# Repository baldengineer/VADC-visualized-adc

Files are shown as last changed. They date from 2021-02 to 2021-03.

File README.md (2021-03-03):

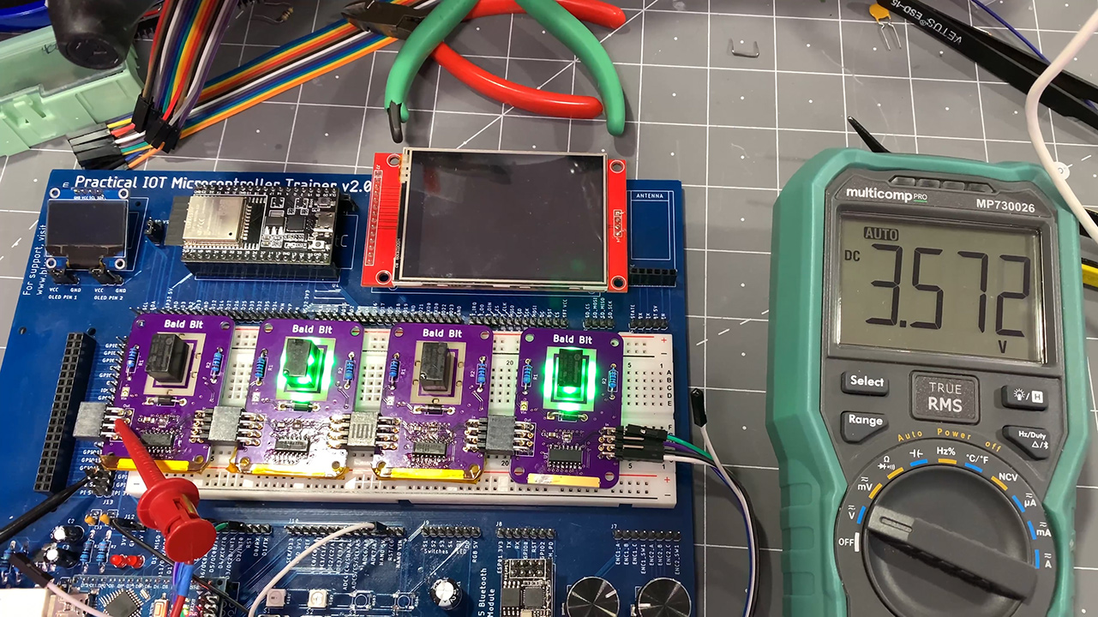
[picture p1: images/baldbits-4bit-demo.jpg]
Early Baldbits Demo


# VADC-visualized-adc
 Hardware project that shows how a SAR ADC works!

## Streaming notes
This project was created as a part of a [Bald Engineer Live Stream](https://twitch.tv/baldengineer). For stream-by-stream notes, [check out this repo](https://bald.ee/60-notes).

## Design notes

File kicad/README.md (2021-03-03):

# Visualized ADC KiCad Design Files
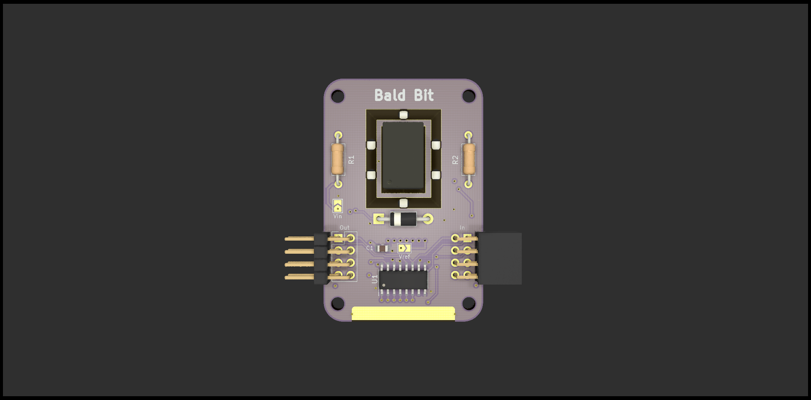
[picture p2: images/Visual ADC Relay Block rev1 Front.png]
Rendered vADC bit board


## Visual ADC Relay Block
Single bit block of the DAC inside of the ADC. The board contains a relay, R resistor, 2R resistor, LEDs, a shift register, and a buffer. 

The shift register and buffer control the relay and six LEDs individually. The relay controls the 2R resistor. 

The idea is to daisy chain these together. (So far, only tested with 4 bits.)

Board was fabricated with OSH Park's 4 layer service. The fiberglass material helps the reverse-mount LEDs glow.

## Sample-Hold-Compare
These files are schematic-only. I captured the breadboard circuit we used for the sample-and-hold amplifier and op-amp as a comparator.

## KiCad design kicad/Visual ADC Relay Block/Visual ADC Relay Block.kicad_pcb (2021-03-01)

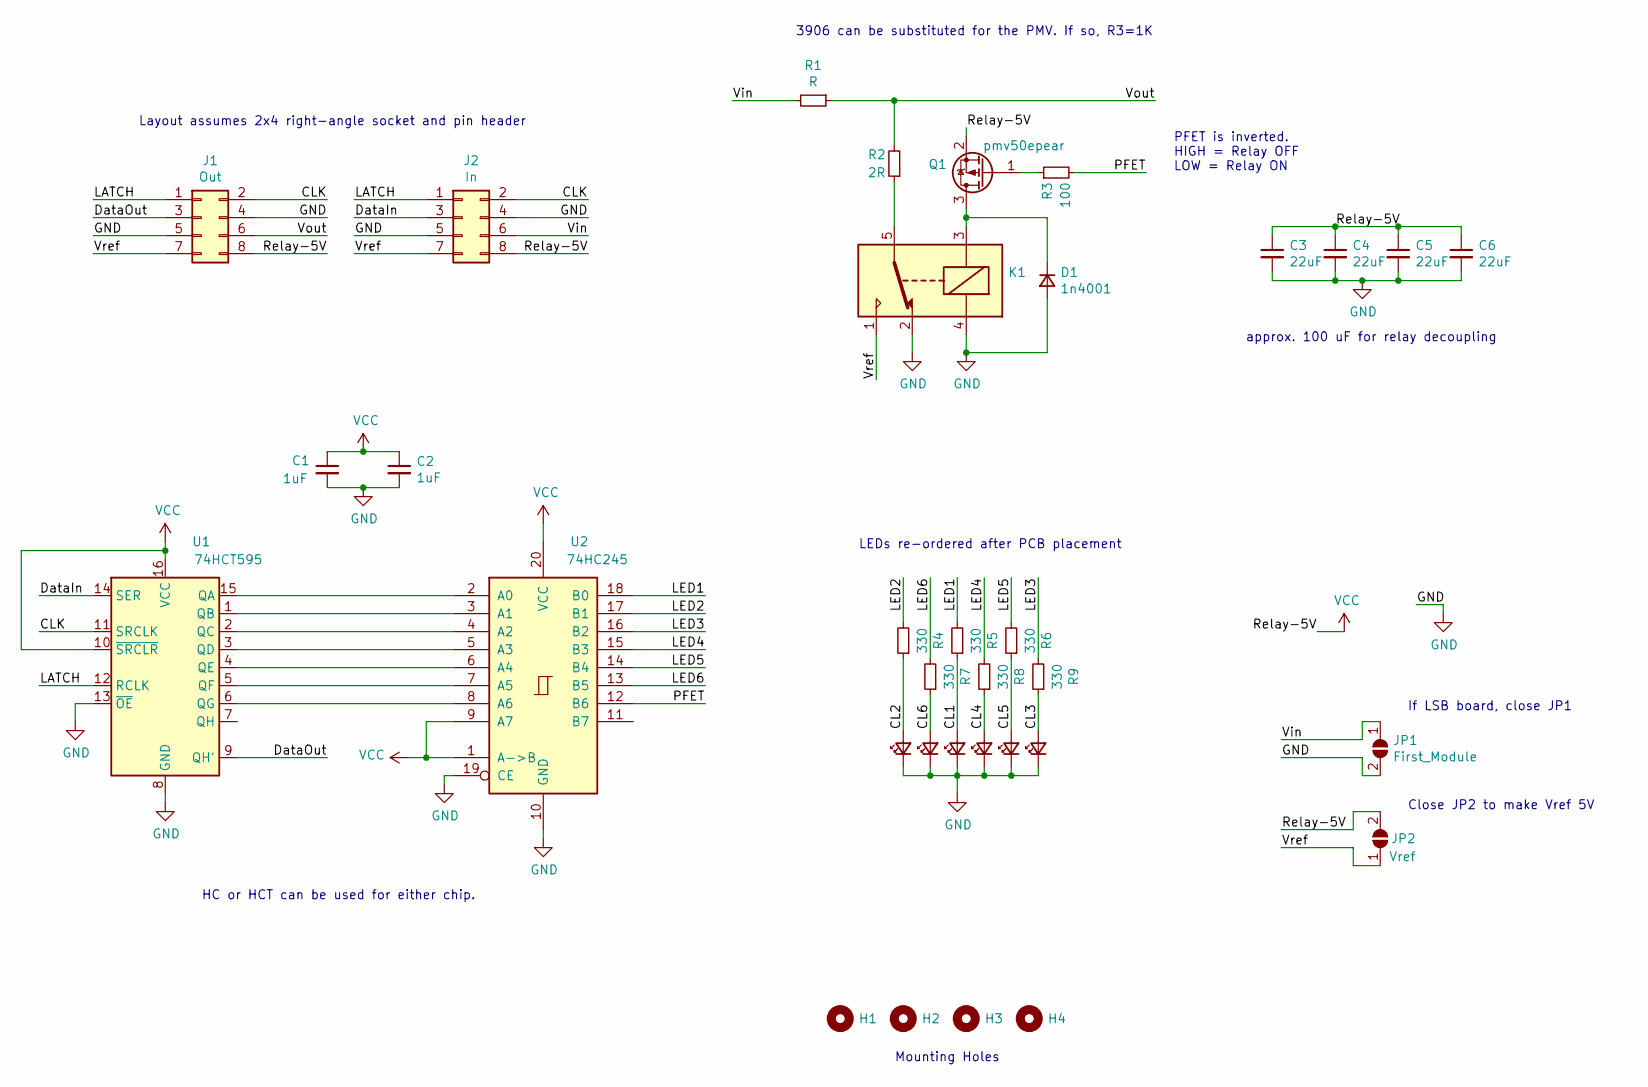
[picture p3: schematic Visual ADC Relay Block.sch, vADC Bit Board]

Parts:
C1, C2: 1uF; C_0805_2012Metric_Pad1.18x1.45mm_HandSolder
C3, C4, C5, C6: 22uF; C_0805_2012Metric_Pad1.18x1.45mm_HandSolder
D1: 1n4001; D_DO-41_SOD81_P10.16mm_Horizontal
D2, D3, D4, D5, D6, D7: LED_Small; LED_1206_3216Metric_ReverseMount_Hole1.8x2.4mm
H1, H2, H3, H4: MountingHole; MountingHole_2.7mm
J1: Out; PinHeader_2x04_P2.54mm_Vertical
J2: In; PinHeader_2x04_P2.54mm_Vertical
JP1: First_Module; SolderJumper-2_P1.3mm_Open_TrianglePad1.0x1.5mm
JP2: Vref; SolderJumper-2_P1.3mm_Open_TrianglePad1.0x1.5mm
K1: DIPxx-1Cxx-51x; Relay_SPDT_HsinDa_Y14
Q1: pmv50epear; SOT-23
R1: R; R_Axial_DIN0207_L6.3mm_D2.5mm_P10.16mm_Horizontal
R2: 2R; R_Axial_DIN0207_L6.3mm_D2.5mm_P10.16mm_Horizontal
R3: 100; R_0805_2012Metric_Pad1.20x1.40mm_HandSolder
R4, R5, R6, R7, R8, R9: 330; R_0805_2012Metric_Pad1.20x1.40mm_HandSolder
U1: 74HCT595; SO-16_3.9x9.9mm_P1.27mm
U2: 74HC245; SOIC-20W_7.5x12.8mm_P1.27mm

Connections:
/CL1: D3.2 (A), R5.1
/CL2: D4.2 (A), R4.1
/CL3: D5.2 (A), R9.1
/CL4: D6.2 (A), R8.1
/CL5: D7.2 (A), R6.1
/CL6: D2.2 (A), R7.1
/CLK: J1.2, J2.2, U1.11 (SRCLK)
/DataIn: J2.3, U1.14 (SER)
/DataOut: J1.3, U1.9 (QH')
/LATCH: J1.1, J2.1, U1.12 (RCLK)
/LED1: R5.2, U2.18 (B0)
/LED2: R4.2, U2.17 (B1)
/LED3: R9.2, U2.16 (B2)
/LED4: R8.2, U2.15 (B3)
/LED5: R6.2, U2.14 (B4)
/LED6: R7.2, U2.13 (B5)
/PFET: R3.2, U2.12 (B6)
/Vin: J2.6, JP1.1 (A), R1.2
/Vout: J1.6, R1.1, R2.2
/Vref: J1.7, J2.7, JP2.1 (A), K1.1
GND: C1.2, C2.2, C3.2, C4.2, C5.2, C6.2, D1.2 (A), D2.1 (K), D3.1 (K), D4.1 (K), D5.1 (K), D6.1 (K), D7.1 (K), J1.4, J1.5, J2.4, J2.5, JP1.2 (B), K1.2, K1.4, U1.8 (GND), U1.13 (~OE), U2.10 (GND), U2.19 (CE)
unnamed: D1.1 (K), K1.3, Q1.3 (D)
unnamed: K1.5, K1.6, R2.1
unnamed: Q1.1 (G), R3.1
unnamed: U1.1 (QB), U2.3 (A1)
unnamed: U1.2 (QC), U2.4 (A2)
unnamed: U1.3 (QD), U2.5 (A3)
unnamed: U1.4 (QE), U2.6 (A4)
unnamed: U1.5 (QF), U2.7 (A5)
unnamed: U1.6 (QG), U2.8 (A6)
unnamed: U1.15 (QA), U2.2 (A0)
VCC: C1.1, C2.1, C3.1, C4.1, C5.1, C6.1, J1.8, J2.8, JP2.2 (B), Q1.2 (S), U1.10 (~SRCLR), U1.16 (VCC), U2.1 (A->B), U2.9 (A7), U2.20 (VCC)

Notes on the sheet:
3906 can be substituted for the PMV. If so, R3=1K
If LSB board, close JP1
Close JP2 to make Vref 5V
LEDs re-ordered after PCB placement
PFET is inverted. HIGH = Relay OFF LOW = Relay ON
approx. 100 uF for relay decoupling
Layout assumes 2x4 right-angle socket and pin header
HC or HCT can be used for either chip.
Mounting Holes

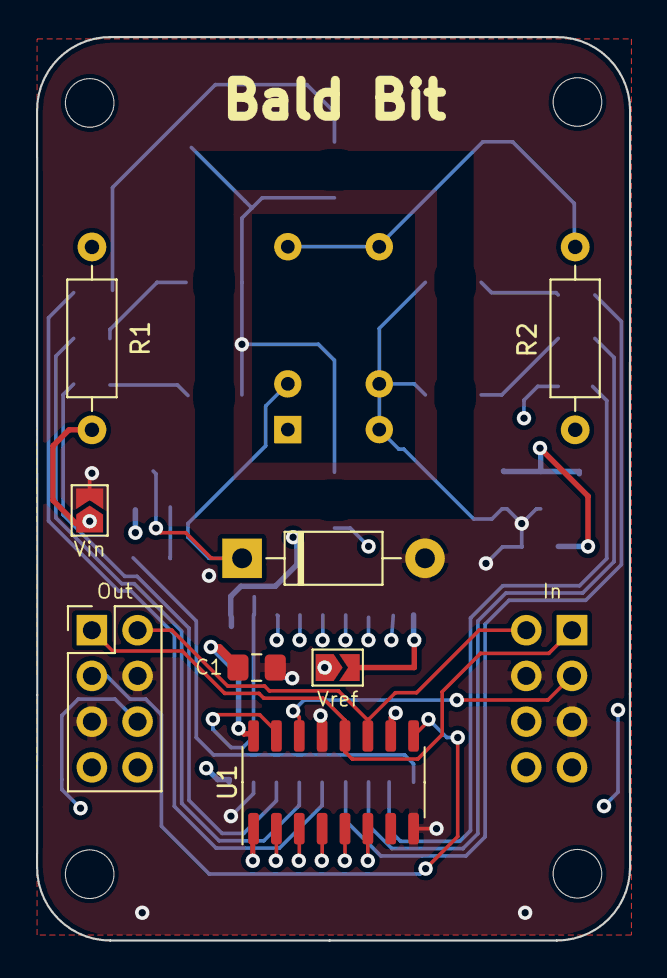
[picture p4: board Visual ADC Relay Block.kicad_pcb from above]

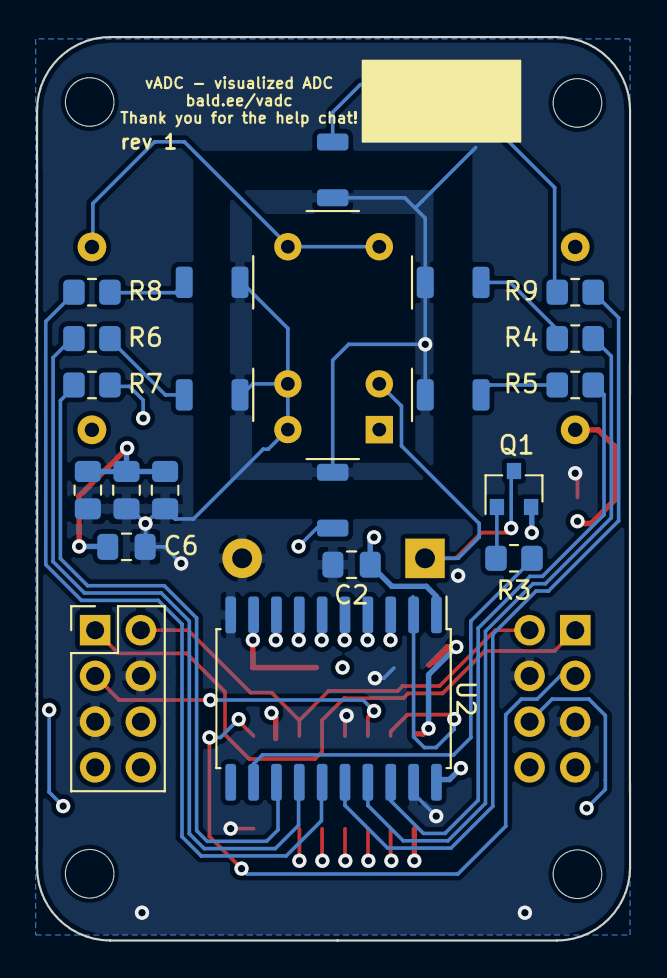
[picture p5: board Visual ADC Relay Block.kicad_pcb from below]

Board: 4 copper layers, 32.9 x 50.2 mm, 34 parts (21 on the bottom side), 32 nets.

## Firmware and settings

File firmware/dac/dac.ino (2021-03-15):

#include "dac.h"
#include "tft.h"

void handle_serial() {
  if (Serial.available()) {
    if (Serial.peek() != '!') {
      int dac_value = Serial.parseInt();

      if (dac_value < 0)
        dac_value = 0;
      if (dac_value > 0xF)
        dac_value = 0xF;
      Serial.print("Got: "); Serial.println(dac_value);

      send_data_to_bits(convert_to_bit(dac_value));	
    } else {
      Serial.read();
      digitalWrite(sh_enable, HIGH);
      delay(5);
      digitalWrite(sh_enable, LOW);
      Serial.println("Sampled");
    }
  }	
}

void init_595() {
	pinMode(clock_595, OUTPUT);
	pinMode(latch_595, OUTPUT);
	pinMode(data_595, OUTPUT);

	digitalWrite(clock_595, LOW);
	digitalWrite(data_595, LOW);
	digitalWrite(latch_595, HIGH);


	uint32_t data_out=0x0;
	data_out = set_relay(data_out, RELAY_ON, 0);
	data_out = set_relay(data_out, RELAY_ON, 1);
	data_out = set_relay(data_out, RELAY_ON, 2);
	data_out = set_relay(data_out, RELAY_ON, 3);

	send_data_to_bits(data_out);
}

uint32_t set_relay(uint32_t data_stream, bool state, int relay_number) {
	int shift_by = (relay_number * 8) + 6;
	bitWrite(data_stream, shift_by, !state);
	Serial.print(relay_number); Serial.print(": "); Serial.println(data_stream, HEX);
	return data_stream;
}

void send_data_to_bits(uint32_t data_out) {
	// X R X X  X X X 1  X R X X  X X X 1   X R X X  X X X 1   X R X X  X X X 1
	digitalWrite(latch_595, LOW);
 	 shiftOut(data_595, clock_595, MSBFIRST, (data_out >> 24));  // bit 4
	 shiftOut(data_595, clock_595, MSBFIRST, (data_out >> 16));  // bit 3
	 shiftOut(data_595, clock_595, MSBFIRST, (data_out >> 8));	// bit 2
	 shiftOut(data_595, clock_595, MSBFIRST, (data_out));		// bit 0
	digitalWrite(latch_595, HIGH);

  // give the relays time to settle
  delay(10);
}

double measure_dac_value() {
  return analogRead(A5) * (adc_vref/(pow(2,10)));
}

void print_dac_and_binary(uint16_t color, char *msg) {
  char str_val[8] = {"0.00v"}; // = "00.00v";
  double current_dac_voltage = measure_dac_value();
  Serial.print(F("current_dac_voltage = ")); Serial.print(current_dac_voltage); Serial.println(F(" volts)"));
  dtostrf(current_dac_voltage, 5, 2, str_val);
  tft_print_twolines(str_val, color, msg, color); 
}

void print_dac_value(uint16_t color) {
  char str_val[8] = {"0.00v"}; // = "00.00v";
  double current_dac_voltage = measure_dac_value();
  Serial.print(F("current_dac_voltage = ")); Serial.print(current_dac_voltage); Serial.println(F(" volts)"));
  dtostrf(current_dac_voltage, 5, 2, str_val);
  tft_print_oneline(str_val, color);
}

uint32_t convert_to_bit(byte counter) {
	uint32_t data_out = 0x0;
	
	switch(counter) {
	    case 0:
	      data_out = 0x40404040;
	      break;
	    case 1:
	      data_out = 0x404040BF;  // 1011 111
	      break; 
	    case 2:
	      data_out = 0x4040BF40;
	      break;
	    case 3:
	      data_out = 0x4040BFBF;
	      break;
	    case 4:
	      data_out = 0x40BF4040;
	      break;
	    case 5:
	      data_out = 0x40BF40BF;
	      break;
	    case 6:
	      data_out = 0x40BFBF40;
	      break;
	    case 7:
	      data_out = 0x40BFBFBF;
	      break;
	    case 8:
	      data_out = 0xBF404040;
	      break;
	    case 9:
	      data_out = 0xBF4040BF;
	      break;
	    case 10:
	      data_out = 0xBF40BF40;
	      break;  
	    case 11:
	      data_out = 0xBF40BFBF;
	      break;  
	    case 12:
	      data_out = 0xBFBF4040;
	      break;
	    case 13:
	      data_out = 0xBFBF40BF;
	      break;  
	    case 14:
	      data_out = 0xBFBFBF40;
	      break;  
	    case 15:
	      data_out = 0xBFBFBFBF;
	      break;  
	  }
	return data_out;
}

void sample_vin() {
  digitalWrite(sh_enable, HIGH);
  delay(500);
  digitalWrite(sh_enable, LOW);
}

void dac_cal() {
  int cal_delay = 100;
  // clear the relays
  char msg[6] = {"Cal"};
  tft_print_oneline(msg, LCD_RED);
  send_data_to_bits(convert_to_bit(0)); // clear, good for scope view
  delay(cal_delay);

  // set 15, measure the voltage
  send_data_to_bits(convert_to_bit(15)); // clear, good for scope view
  delay(cal_delay);
  dac_value_max = measure_dac_value();

  // set 8, measure the voltage
  send_data_to_bits(convert_to_bit(8)); // clear, good for scope view
  delay(cal_delay);
  double dac_value_verify = measure_dac_value();

  // set 1, measure the voltage
  send_data_to_bits(convert_to_bit(1)); // clear, good for scope view
  delay(cal_delay);
  dac_value_step = measure_dac_value();

  // set 0, measure the voltage
  send_data_to_bits(convert_to_bit(0)); // clear, good for scope view
  delay(cal_delay);
  dac_value_min = measure_dac_value();


  char step_str[8];
  dtostrf(dac_value_step, 5, 2, step_str);
  char verify_str[8];
  dtostrf((dac_value_verify/8.0), 5, 2, verify_str);

  send_data_to_bits(convert_to_bit(0));

  tft_print_twolines(step_str, LCD_BLUE, verify_str, LCD_GREEN);

  delay(1000);
  tft_print_oneline(msg_ready, LCD_BLUE);

}

void setup() {
	Serial.begin(9600);
	Serial.println(F("Visualized ADC - DAC"));
	init_595();
	init_tft();

  analogReference(EXTERNAL);
  analogRead(A0);

	pinMode(sh_enable, OUTPUT);
	digitalWrite(sh_enable, LOW);
	pinMode(comparator_result, INPUT);

  pinMode(step_button, INPUT_PULLUP);
	pinMode(cal_button, INPUT_PULLUP);
	pinMode(button, INPUT_PULLUP);

  dac_cal();
}



void led_blink(byte bit, byte test_value) {
  static unsigned long previous_led_blink=0;
  static bool led_state = false;
  unsigned long led_invterval = 50;
  unsigned long current_millis = millis();
  if (current_millis - previous_led_blink >= led_invterval) {
    uint32_t data_stream = convert_to_bit(test_value);
    if (led_state) {
      led_state = false;
      //0x40;
      bitWrite(data_stream, ((bit*8)-1), 0);  // 4*8, 32-1 = 31
      bitWrite(data_stream, ((bit*8)-2), 0);  // 4*8, 32-2 = 30
      bitWrite(data_stream, ((bit*8)-3), 0);
      bitWrite(data_stream, ((bit*8)-4), 0);
      bitWrite(data_stream, ((bit*8)-5), 0);
      bitWrite(data_stream, ((bit*8)-6), 0);
      bitWrite(data_stream, ((bit*8)-7), 0);
      bitWrite(data_stream, ((bit*8)-8), 0);  // 48*-8, 32-8 = 24
    } else {
      led_state = true;  // 0xBF
      bitWrite(data_stream, ((bit*8)-1), 1);  // 4*8, 32-1 = 31
      bitWrite(data_stream, ((bit*8)-2), 0);  // 4*8, 32-2 = 30
      bitWrite(data_stream, ((bit*8)-3), 1);
      bitWrite(data_stream, ((bit*8)-4), 1);
      bitWrite(data_stream, ((bit*8)-5), 1);
      bitWrite(data_stream, ((bit*8)-6), 1);
      bitWrite(data_stream, ((bit*8)-7), 1);
      bitWrite(data_stream, ((bit*8)-8), 1);  // 48*-8, 32-8 = 24
    }
   // set_relay(data_stream, true, bit);  // uint32_t data_stream, bool state, int relay_number
    send_data_to_bits(data_stream);
    previous_led_blink = current_millis;
  }

}

void loop() {
  unsigned long current_millis = millis();

  handle_serial();

  // Print current DAC value (mostly for testing)
  if (digitalRead(cal_button) == PRESSED)
    dac_cal();

  // manual stepper mode, go one step at a time.
  if (digitalRead(step_button) == PRESSED) {
   stepper = true;
   start_SAR = true;
  }

  // kick-off the conversion
	if (digitalRead(button) == PRESSED) {
		start_SAR = true;
	}

	// start conversion
	if (start_SAR) {
    send_data_to_bits(convert_to_bit(0)); // clear, good for scope view
    print_dac_value(LCD_BLUE);
		start_SAR = false;
    Serial.println(F("---\nConversion Start:"));
    Serial.print(F("vref = ")); Serial.println(adc_vref);
    Serial.print(F("adc_voltage_step = ")); Serial.println(adc_voltage_step);

		// sample Vin
    sample_vin();

		final_countdown = 0;

    // string to display bit sequence on LCD
    char bit_sequence[dac_width+1]; 
    for (int x=0; x<dac_width; x++)
      bit_sequence[x] = '?';
    bit_sequence[dac_width+1] = '\0';

    // test one bit at a time, going from MSB to LSB
    const byte remap[] = {3,2,1,0};
		for (int x=(dac_width-1); x>=0; x--) {
      // test the current  bit
			bitWrite(final_countdown, x, 1);
			send_data_to_bits(convert_to_bit(final_countdown));
      delay(10);
      bit_sequence[remap[x]] = 'X';
      //print_dac_value(LCD_BLUE); // red is actually blue
      print_dac_and_binary(LCD_BLUE, bit_sequence);

      if (stepper) 
        while(digitalRead(step_button) == NOT_PRESSED)
          led_blink((x+1), final_countdown);
      else 
        //delay(500);
        for (int ticks=0; ticks<500; ticks++) {
          led_blink((x+1), final_countdown);
          delay(1);
        }
          
      // capture comparator result, finalizing the current bit
      if (digitalRead(comparator_result)) {
		  	bitWrite(final_countdown, x, HIGH);
        bit_sequence[remap[x]] = '1';
      } else {
		  	bitWrite(final_countdown, x, LOW);
        bit_sequence[remap[x]] = '0';        
      }


      print_dac_and_binary(LCD_BLUE, bit_sequence);  
		}
	
		// send final value	
    if (stepper) while(digitalRead(step_button) == NOT_PRESSED);
		send_data_to_bits(convert_to_bit(final_countdown));
    delay(10);

    char low_value[8];
    char high_value[8];

    dtostrf((dac_value_step * final_countdown),  3, 1, low_value);
    dtostrf(((dac_value_step * final_countdown) + dac_value_step), 3, 1, high_value );
    char line1[8];
    sprintf(line1, "%s-%s", low_value, high_value);

   // print_dac_value(LCD_RED);
//    tft_print_twolines(low_value, LCD_GREEN, high_value, LCD_RED);
    tft_print_twolines(line1, LCD_GREEN, bit_sequence, LCD_BLUE);

		Serial.print(F("Conversion: ")); Serial.print(final_countdown);
		Serial.print(F(","));
		Serial.print(final_countdown * 0.3);
		Serial.println(F("V"));
    stepper = false;
	}
}

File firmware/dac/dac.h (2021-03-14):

#include <Arduino.h>

// for the TFT
#include <Adafruit_GFX.h>    // Core graphics library
#include <Adafruit_ST7735.h> // Hardware-specific library for ST7735
#include <SPI.h>
//#include <Fonts/FreeMonoBoldOblique12pt7b.h>
//#include <Fonts/FreeSansBold24pt7b.h>	
#include <Fonts/FreeSansBold18pt7b.h>
#include <String.h>

#define RELAY_ON false
#define RELAY_OFF true

// 595 bit that contains the relay
#define relay_mask 0x40

// Shift Register Bits
const byte clock_595 = 2;
const byte latch_595 = 3;
const byte data_595 = 4;

// Front-End Variables
const byte sh_enable = 8;
const byte comparator_result = 7;

// SAR variables
bool start_SAR = false;
uint8_t final_countdown =0;
const byte dac_width = 4;
double adc_vref = 4.98;
double adc_voltage_step = adc_vref / ((pow(2,dac_width)-1.0));
int comparator_value = 0;

double dac_value_min = 0.0;
double dac_value_max = 0.0;
double dac_value_step = 0.0;

unsigned long previous_print_millis = 0;
unsigned long print_interval = 1000;

// Test Pattern variables
int wait = 2500;
byte counter = 0x0;
const byte button = 6;
const byte cal_button =  A3;
const byte step_button = A4;
const byte vref_input = A1;

bool stepper = false;


#define PRESSED LOW
#define NOT_PRESSED HIGH

// Strings
const char msg_ready[8] = {"Ready"};

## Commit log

2021-02-11 V1 kicad layout
    going to re-work and add shift registers....
    [Visual ADC Relay Block.kicad_pcb, Visual ADC Relay Block.sch]
2021-02-11 before changing to ribbons
    [Visual ADC Relay Block.kicad_pcb, Visual ADC Relay Block.sch]
2021-02-11 time to clean up
    [Visual ADC Relay Block.kicad_pcb, Visual ADC Relay Block.sch]
2021-02-11 why won't you stop
    [Visual ADC Relay Block.kicad_pcb, Visual ADC Relay Block.sch]
2021-02-11 Passed DRC and No Rats
    [Visual ADC Relay Block.kicad_pcb, Visual ADC Relay Block.sch]
2021-02-11 Silk clean up
    [Visual ADC Relay Block.kicad_pcb]
2021-02-14 change in/out but need to save brains
    [Visual ADC Relay Block.kicad_pcb, Visual ADC Relay Block.sch]
2021-02-14 pass DRC yay!
    [Visual ADC Relay Block.kicad_pcb, Visual ADC Relay Block.sch]
2021-02-14 relay masks done
    outline around relay area with no copper or mask on any layer
    [Visual ADC Relay Block.kicad_pcb]
2021-02-14 added probe gnd now silky time
    [Visual ADC Relay Block.kicad_pcb]
2021-02-14 rev1 pre-submit
    haven't submitted rev to board house yet
    [Visual ADC Relay Block.kicad_pcb]
2021-02-28 rev1 boards tested
    [Sample-Hold-Compare.kicad_pcb, Sample-Hold-Compare.sch, Visual ADC Relay Block.kicad_pcb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]
2021-03-01 KiCad Notes and Clean-up
    Finalized a few details on the schematic. Also created notes for each block based on experience building the boards.
    [Visual ADC Relay Block.kicad_pcb, Visual ADC Relay Block.sch]
2021-03-03 create readme for KiCad files
2021-03-06 stream 21-03-05
    [Sample-Hold-Compare.sch, Visual ADC Relay Block.sch]
2021-03-11 what the what
    erroring out with: relocation truncated to fit: R_AVR_7_PCREL against `no symbol'
    [dac.h, dac.ino, tft.ino]
2021-03-11 post-stream clean-up (untested)
    cleaned up some potential problems based on the stream 3/10, still need to test.
    [dac.h, dac.ino, tft.ino]
2021-03-12 cal and bug fixes
    Fixed a bug with the step-by-step mode. Added external reference for the ADC (tied to regulator output), added range/two-line output when conversion is complete.
    [dac.h, dac.ino]
2021-03-14 bug fixes
    changed DAC voltage display code to use global variable. hardware wise, added heat sink to LM7805. It was having trouble regulating voltage.
    [dac.h, dac.ino, tft.ino]
2021-03-15 added moar blinky
    When a bit is being tested during the binary search, its LEDs now blink.
    The screen readout is now 2 lines during the search. First line is current DAC voltage and the second line is the binary code so far with ?, X, 0, and 1 indicators.
